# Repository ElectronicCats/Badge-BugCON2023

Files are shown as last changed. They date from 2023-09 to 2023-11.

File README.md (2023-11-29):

# Badge BugCON 2023

Badge de la resistencia BugCON 2023 #unetealaresistencia

## Características

- ESP32S3 o RP2040
- UART
- Bluetooth (ESP32S3)
- WiFi (ESP32S3)
- Baterias AA

## License
<a>
  
</a>

Diseñado por Electronic Cats para BugCON 2023

Electronic Cats invests time and resources in providing this open-source design. Please support Electronic Cats and open-source hardware by purchasing products from Electronic Cats!

Hardware released under an CERN Open Hardware Licence v1.2. See the LICENSE_HARDWARE file for more information.

Electronic Cats and BugCON is a registered trademark. Please do not use if you sell these PCBs.

Sept 2023

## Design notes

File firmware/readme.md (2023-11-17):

# Badge BugCON 2023

Link: https://github.com/ElectronicCats/Badge-BugCON2023

Author(s): Francisco Torres

Last updated: 2023/11/09

## Developer guide

## Setup

### Libraries required

Install the following libraries:

- [Adafruit GFX Library](https://www.arduino.cc/reference/en/libraries/adafruit-gfx-library/)
- [Adafruit BusIO](https://www.arduino.cc/reference/en/libraries/adafruit-busio/)
- [Adafruit NeoPixel](https://www.arduino.cc/reference/en/libraries/adafruit-neopixel/)
- [Adafruit SSD1306](https://www.arduino.cc/reference/en/libraries/adafruit-ssd1306/)
- [ezButton](https://www.arduino.cc/reference/en/libraries/ezbutton/)
- [ArduinoUniqueID](https://www.arduino.cc/reference/en/libraries/arduinouniqueid/)
- [Adafruit SH110X](https://www.arduino.cc/reference/en/libraries/adafruit-sh110x/)

> You can install these libraries using the Arduino IDE Library Manager (Sketch > Include Library > Manage Libraries...).

Versions used in this project:

```bash
Used library         Version    
Adafruit GFX Library 1.11.7
Adafruit BusIO       1.14.3
Wire
SPI
Adafruit NeoPixel    1.11.0
Adafruit SH110X      2.1.8
Adafruit SSD1306     2.5.7
ezButton             1.0.4
ArduinoUniqueID      1.3.0
```

> You can use latest versions of these libraries.

### Modify I2C pins

In order to use the SSD1306 display, you need to modify the I2C pins in `pins_arduino.h` to match the ones used in these boards.

You can locate this file in the following path (depending on your OS):

#### For RP2040

- Windows: `C:\Users\user\AppData\Local\Arduino15\packages\arduino\hardware\mbed_rp2040\4.0.6\variants\RASPBERRY_PI_PICO\pins_arduino.h`
- Linux: `~/.arduino15/packages/arduino/hardware/mbed_rp2040/4.0.6/variants/RASPBERRY_PI_PICO/pins_arduino.h`
- macOS: `~/Library/Arduino15/packages/arduino/hardware/mbed_rp2040/4.0.6/variants/RASPBERRY_PI_PICO/pins_arduino.h`

You can keep the original pins commented out, and add the following lines:

```cpp
// Wire
// #define PIN_WIRE_SDA        (4u)
// #define PIN_WIRE_SCL        (5u)
#define PIN_WIRE_SDA        (12u)
#define PIN_WIRE_SCL        (13u)
```

#### For ESP32-S3

- Windows: `C:\Users\user\AppData\Local\Arduino15\packages\esp32\hardware\esp32\2.0.11\variants\esp32s3\pins_arduino.h`
- Linux: `~/.arduino15/packages/esp32/hardware/esp32/2.0.11/variants/esp32s3/pins_arduino.h`
- macOS: `~/Library/Arduino15/packages/esp32/hardware/esp32/2.0.11/variants/esp32s3/pins_arduino.h`

You can keep the original pins commented out, and add the following lines:

```cpp
// static const uint8_t SDA = 8;
// static const uint8_t SCL = 9;
static const uint8_t SDA = 3;
static const uint8_t SCL = 4;
```

### Fix SSD1306 error

Try to compile the project, if you get the following error:

```bash
❯ make compile BOARD=rp2040
arduino-cli compile --fqbn arduino:mbed_rp2040:pico --export-binaries
/Users/deimos/Documents/Arduino/libraries/Adafruit_SSD1306/Adafruit_SSD1306.cpp:42:10: fatal error: pgmspace.h: No such file or directory
 #include <pgmspace.h>
          ^~~~~~~~~~~~
compilation terminated.
```

You need to fix the following error by commenting out the following line in `Adafruit_SSD1306.cpp`:

```cpp
#include <avr/pgmspace.h>
#elif defined(ESP8266) || defined(ESP32) || defined(ARDUINO_ARCH_RP2040)
// #include <pgmspace.h>
#else
```

> More about this error: https://github.com/adafruit/Adafruit_SSD1306/issues/259

### Production

In `hardware.h` change the following lines:

```cpp
// #define BUTTON_RIGHT 26  // GPIO26 -> For development in Raspberry Pi Pico
#define BUTTON_RIGHT 25  // GPIO25 -> For production in BugCON badge

// #define NEOPIXELS_PIN 16  // GPIO23 -> For development in Raspberry Pi Pico
#define NEOPIXELS_PIN 23  // For production in BugCON badge
```

If `MININO` is defined, commented out:

```cpp
#ifdef USB_VID
    #define BOARD_NAME "ESP32-S3"
    #define ESP32_S3
    // #define MININO
#else
```

Disable waiting for serial port in `menu.cpp` in `begin()` function:

```cpp
debug.waitForSerialConnection();
```

### Compile and flash

Generate binaries for each board:

```bash
make compile BOARD=rp2040
```

```bash
make compile BOARD=esp32s3
```

Compile and flash the binaries to the boards:

```bash
make all BOARD=rp2040
```

```bash
make all BOARD=esp32s3
```

> Note: Make sure you have the correct port selected in `Makefile` for each board.
 
## Maintainer

<a
href="https://github.com/sponsors/ElectronicCats">



</a>

Electronic Cats invests time and resources providing this open source design, please support Electronic Cats and open-source hardware by purchasing products from Electronic Cats!

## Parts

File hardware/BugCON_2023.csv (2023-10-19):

# | Reference | Qty | Value | Footprint | DNP | LCSC# | manf#
1 | C1 | 1 | 1uF | Capacitor_SMD:C_0603_1608Metric |  | C15849
2 | C2, C3, C4, C5 | 4 | 10uF | Capacitor_SMD:C_0603_1608Metric |  | C85713
3 | D1 | 1 | MBR120 | Diode_SMD:D_SOD-123F |  | C130880 | MBR120LSF
4 | F1 | 1 | 0.5A | Fuse:Fuse_0805_2012Metric |  | - | MFU0805FF00500P100
5 | J1 | 1 | Conn_01x04_Pin | Connector_PinSocket_2.54mm:PinSocket_1x04_P2.54mm_Vertical |  |  | Display OLED 128×32 0.91 I2C SSD1306 Blanco / Azul
6 | J2 | 1 | Conn_01x04_Pin | Connector_PinSocket_2.54mm:PinSocket_1x04_P2.54mm_Vertical
7 | J3 | 1 | Conn_01x02 | Connector_PinSocket_2.54mm:PinSocket_1x02_P2.54mm_Vertical
8 | P1 | 1 | USB_C_Plug_USB2.0 | Connectors:C393939 |  | C2760486 | TYPE-C-31-M-31
9 | Q1 | 1 | DMG3415U-7 | Package_TO_SOT_SMD:SOT-23 |  | C96616 | DMG3415U-7
10 | R1 | 1 | 10K | Resistor_SMD:R_0603_1608Metric |  | C217281 | CR-03JL7---10K
11 | R2, R3 | 2 | 5k1 | Resistor_SMD:R_0603_1608Metric |  | C191782 | ERJ3RBD5101V
12 | R4 | 1 | 100K | Resistor_SMD:R_0603_1608Metric |  | C15458 | WR06X104JTL
13 | SW1 | 1 | RESET | Button_Switch_SMD:SW_SPST_TL3342 |  | C318889
14 | SW2 | 1 | GPIO | Button_Switch_SMD:SW_SPST_TL3342 |  | C318889
15 | SW3 | 1 | ON | Footprint:JS102011SAQN |  | C393937
16 | U1 | 1 | ESP32-S3-WROOM-1U-N16 | RF_Module:ESP32-S3-WROOM-1U |  |  | ESP32-S3-WROOM-1U-N16
17 | U2 | 1 | AP2112K-3.3 | Package_TO_SOT_SMD:SOT-23-5 |  | C150742 | AP7365-33WG-7

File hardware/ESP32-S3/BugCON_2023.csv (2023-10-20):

# | Reference | Qty | Value | Footprint | DNP | LCSC# | manf# | Proveedor
1 | C1 | 1 | 1uF | Capacitor_SMD:C_0603_1608Metric |  | C15849 | CL10A105KB8NNNC | LCSC
2 | C2, C3, C4, C5 | 4 | 10uF | Capacitor_SMD:C_0603_1608Metric |  | C85713 | CL10A106MP8NNNC | LCSC
3 | C6, C7, C8, C9 | 4 | 0.1uF | Capacitor_SMD:C_0603_1608Metric |  | C42998 | 0603F104M500NT | LCSC
4 | D1 | 1 | MBR120 | Diode_SMD:D_SOD-123F |  | C130880 | MBR120LSF | LCSC
5 | D2, D3, D5, D6 | 4 | WS2812B | FootprintsB:LED-SMD_4P-L3.5-W3.5-TL_WS2812B |  | C527089 | WS2812B-Mini | LCSC
6 | F1 | 1 | 0.5A | Fuse:Fuse_0805_2012Metric |  | - | MFU0805FF00500P100 | MOUSER
7 | J1 | 1 | Conn_01x04_Pin | Connector_PinSocket_2.54mm:PinSocket_1x04_P2.54mm_Vertical |  |  | Display OLED 128×32 0.91 I2C SSD1306 Blanco / Azul | Unit Electronics
8 | J3 | 1 | Conn_01x02 | FootprintsB:BAT_12BH331P-GR |  |  | 12BH331P-GR | MOUSER
9 | J4, J5 | 2 | Conn_01x01_Pin | Connector_PinHeader_1.00mm:PinHeader_1x01_P1.00mm_Horizontal | DNP
10 | J6 | 1 | SERIAL | Connector_PinSocket_2.54mm:PinSocket_1x03_P2.54mm_Vertical
11 | P1 | 1 | USB_C_Plug_USB2.0 | FootprintsB:C393939 |  | C2765186 | TYPE-C 16PIN 2MD(073) | LCSC
12 | Q1 | 1 | DMG3415U-7 | Package_TO_SOT_SMD:SOT-23 |  | C96616 | DMG3415U-7 | LCSC
13 | R1 | 1 | 10K | Resistor_SMD:R_0603_1608Metric |  | C309083 | ARG03BTC1002 | LCSC
14 | R2, R3 | 2 | 5k1 | Resistor_SMD:R_0603_1608Metric |  | C191782 | ERJ3RBD5101V | LCSC
15 | R4 | 1 | 100K | Resistor_SMD:R_0603_1608Metric |  | C15458 | 0603WAJ0104T5E | LCSC
16 | R9 | 1 | 470 | Resistor_SMD:R_0603_1608Metric |  | C103661 | RTT03471JTP
17 | SW1 | 1 | RESET | Button_Switch_SMD:SW_SPST_TL3342 |  | C318889 | TS-1187A-C-C-B | LCSC
18 | SW2 | 1 | GPIO | Button_Switch_SMD:SW_SPST_TL3342 |  | C318889 | TS-1187A-C-C-B | LCSC
19 | SW3 | 1 | ON | FootprintsB:SW-TH_SK12D07VG4 |  | C393937 | SK12D07VG4 | LCSC
20 | U1 | 1 | ESP32-S3-WROOM-1-N4 | FootprintsB:XCVR_ESP32-S3-WROOM-1-N8R2 |  |  | ESP32-S3-WROOM-1-N4 | MOUSER
21 | U2 | 1 | AP2112K-3.3 | Package_TO_SOT_SMD:SOT-23-5 |  | C51118 | AP2112K-3.3TRG1 | LCSC

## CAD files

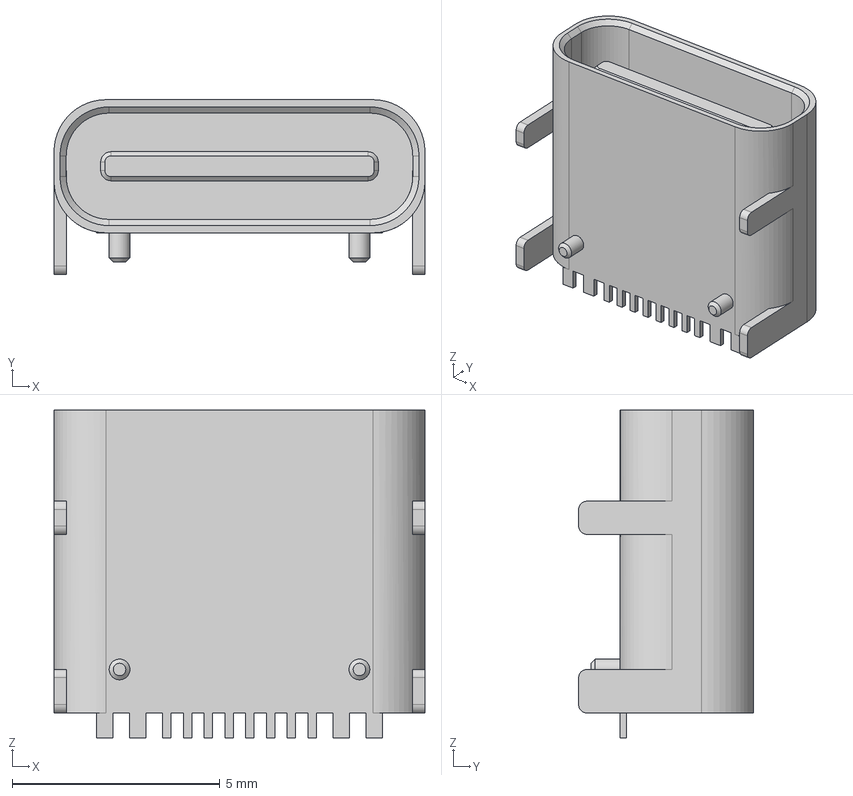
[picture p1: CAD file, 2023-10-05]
hardware/ESP32-S3/FootprintsB/3D/HRO TYPE-C-31-M-12.step
8.94 x 4.21 x 7.90 mm

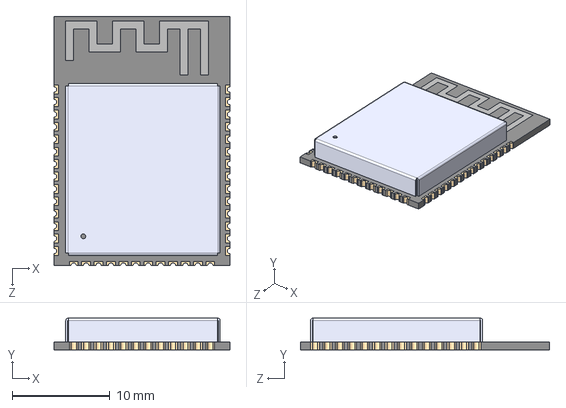
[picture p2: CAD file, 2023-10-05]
hardware/ESP32-S3/FootprintsB/3D/ESP32-S3-WROOM-1-N8R2.step
18.0 x 3.25 x 25.5 mm

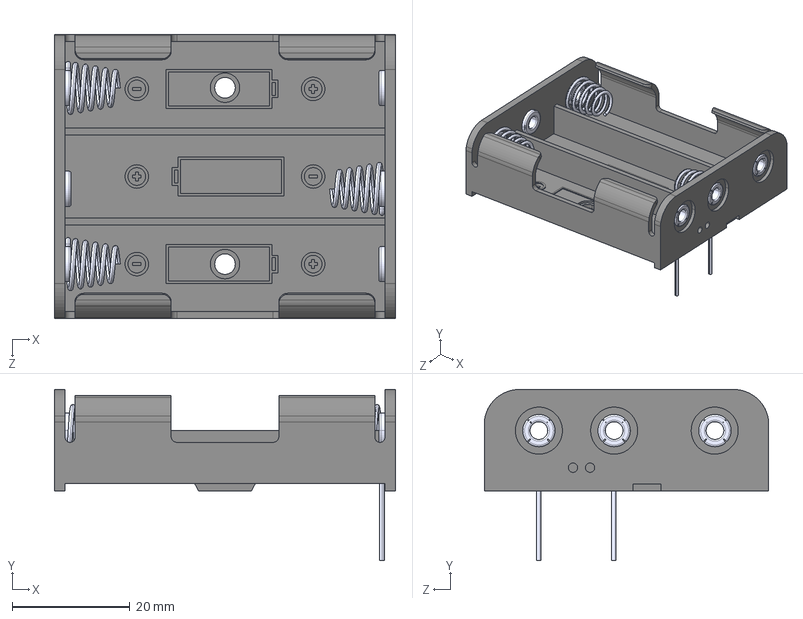
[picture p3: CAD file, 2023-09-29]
hardware/ESP32-S3/FootprintsB/3D/12BH331P-GR--3DModel-STEP-56544.STEP
58.0 x 29.1 x 48.3 mm

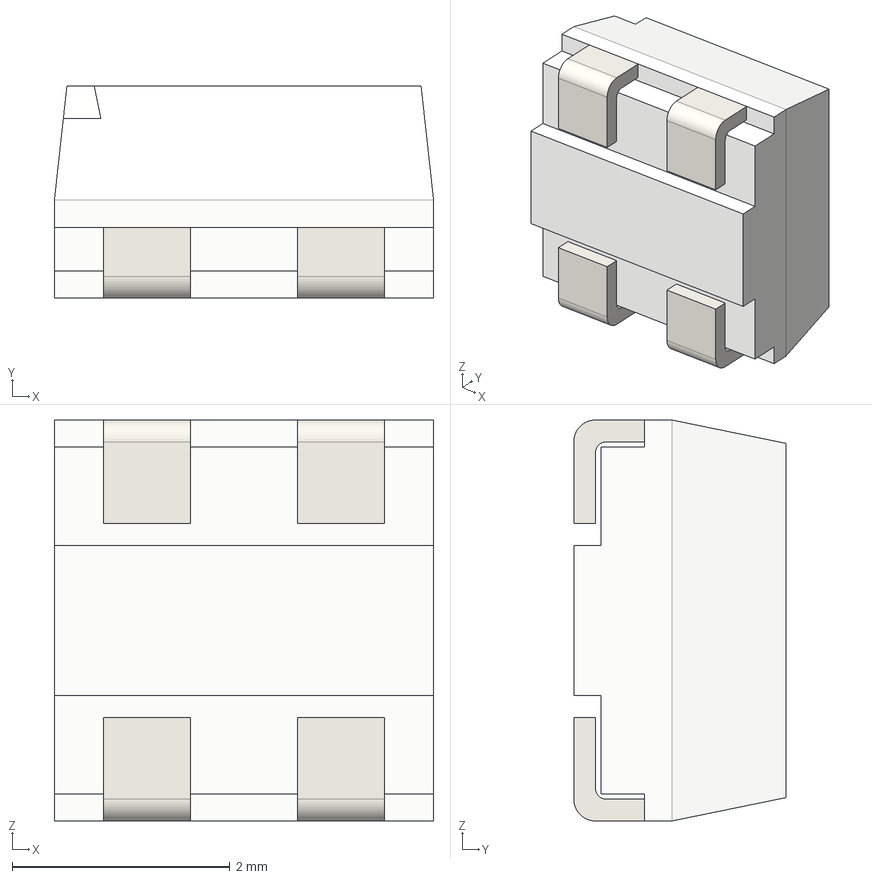
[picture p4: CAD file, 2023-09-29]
hardware/ESP32-S3/FootprintsB/3D/SMD WS2812B Mini.step
3.48 x 1.95 x 3.68 mm

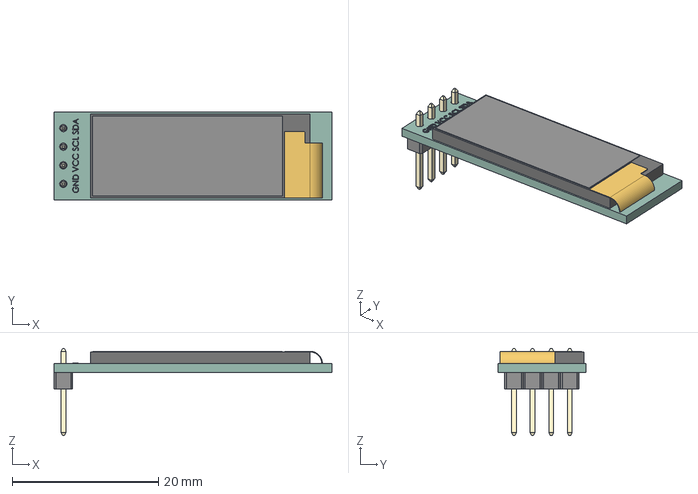
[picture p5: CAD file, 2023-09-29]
hardware/ESP32-S3/FootprintsB/3D/128x32-OLED.STEP
38.0 x 12.0 x 11.9 mm

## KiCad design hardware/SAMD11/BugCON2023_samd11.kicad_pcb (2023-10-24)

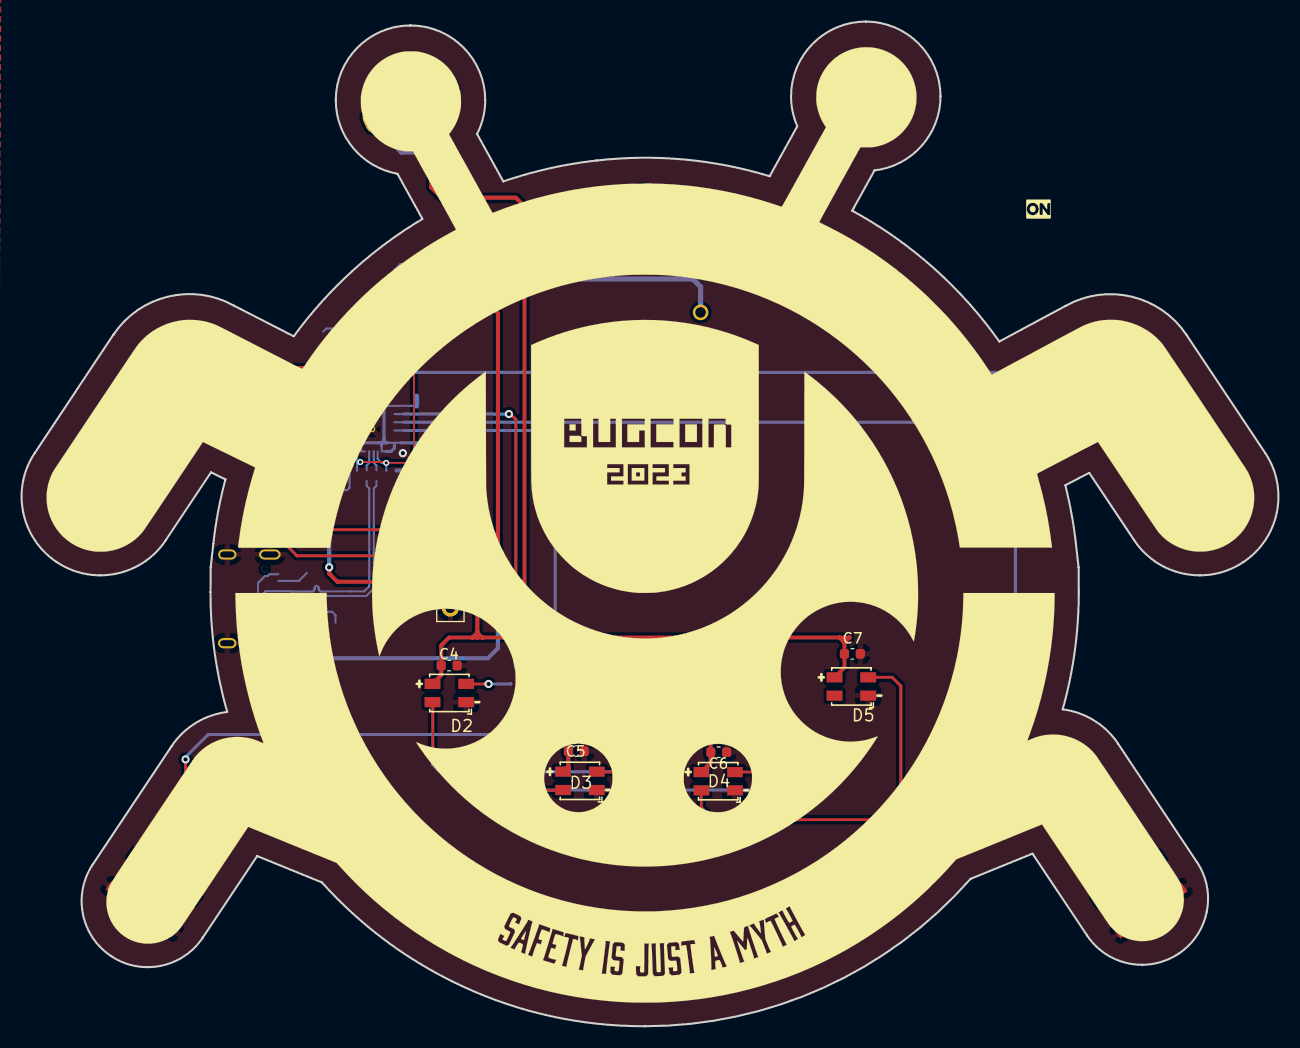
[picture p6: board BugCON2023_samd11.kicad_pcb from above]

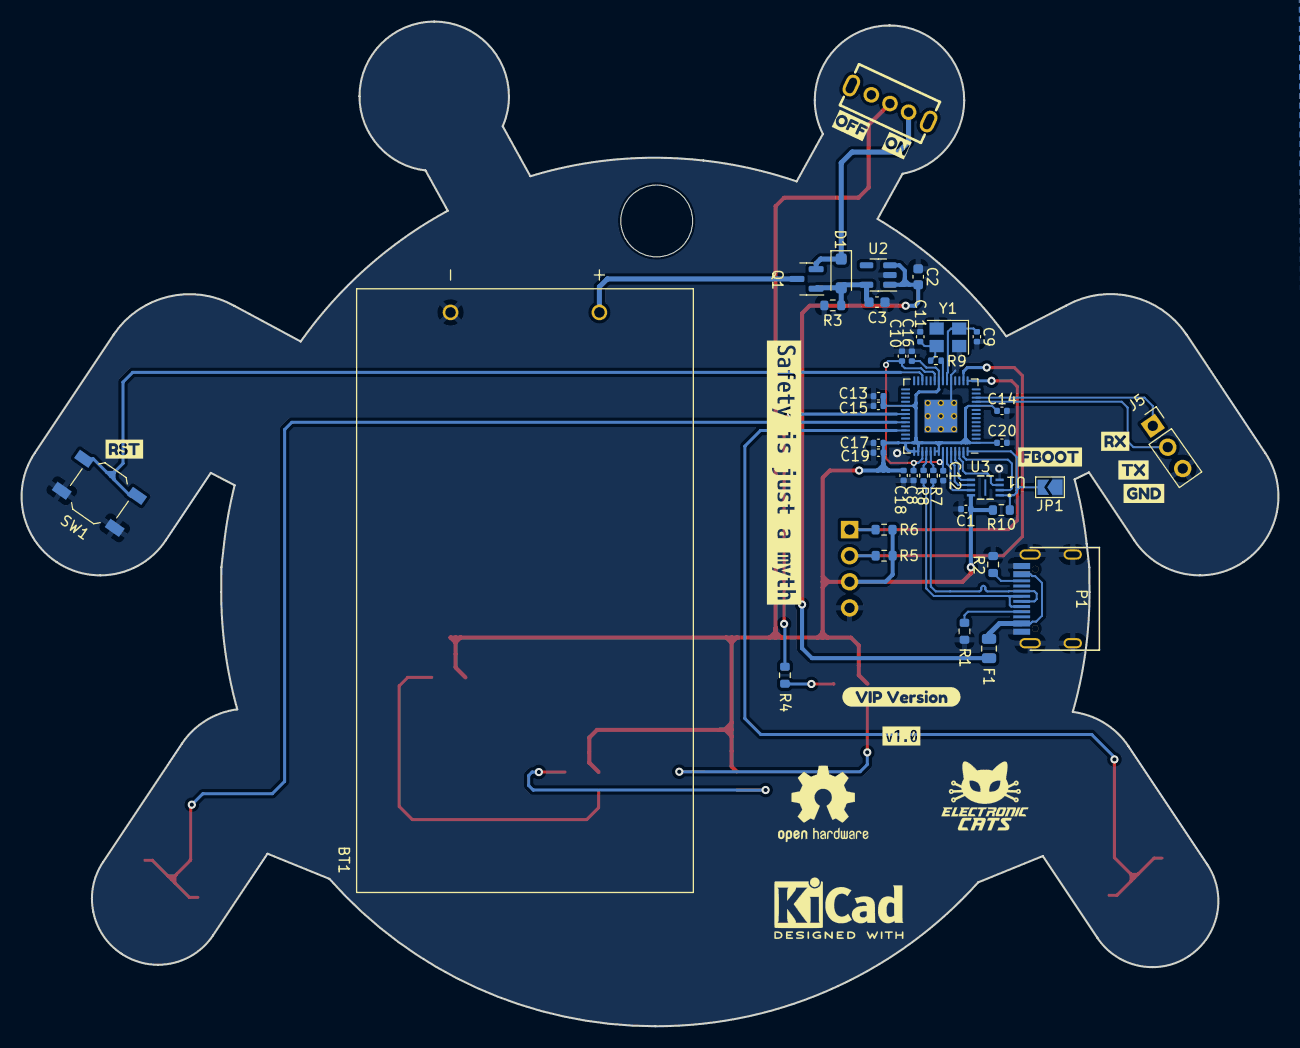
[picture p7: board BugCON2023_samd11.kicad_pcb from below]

Board: 2 copper layers, 122.4 x 97.9 mm, 63 parts (49 on the bottom side), 35 nets.

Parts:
BT1: Battery_Cell; BAT_2462
C1, C10, C12, C14, C15, C16, C17, C18, C19, C20: 0.1uF; C_0402_1005Metric
C2, C3: 10uF; C_0603_1608Metric
C4, C5, C6, C7: 0.1uF; C_0603_1608Metric
C8, C13: 1uF; C_0402_1005Metric
C9, C11: 27pF; C_0402_1005Metric
D1: MBR120; D_SOD-123F
D2, D3, D4, D5: WS2812B; LED-SMD_4P-L3.5-W3.5-TL_WS2812B
F1: 0.5A; Fuse_0805_2012Metric
J1: I2C; PinSocket_1x04_P2.54mm_Vertical
J5: Serial; PinSocket_1x03_P2.54mm_Vertical
JP1: BOOT; SolderJumper-2_P1.3mm_Open_TrianglePad1.0x1.5mm
P1: USB_C_Plug_USB2.0; C393939
Q1: DMG3415U-7; SOT-23
R1, R2: 5k1; R_0603_1608Metric
R3: 100K; R_0603_1608Metric
R4: 470; R_0603_1608Metric
R5, R6: 4.7; R_0603_1608Metric
R7, R8: 27; R_0402_1005Metric
R9: 1k; R_0402_1005Metric
R10: 10K; R_0603_1608Metric
Ref**: Val**; Bugcon_svg
SW1: RESET; SW_SPST_TL3342
SW2: ON; SW-TH_SK12D07VG4
SW3, SW4: SW_Push; SW_SPST_TL3342
U1: W25Q16JV; W25Q16JVUXIQ_WIN
U2: AP2112K-3.3; SOT-23-5
U3: RP2040; QFN-56-1EP_7x7mm_P0.4mm_EP3.2x3.2mm
Y1: 12MHz; Crystal_SMD_3225-4Pin_3.2x2.5mm
kibuzzard-652DCDAF: G***; kibuzzard-652DCDAF
kibuzzard-652DCDD3: G***; kibuzzard-652DCDD3
kibuzzard-652DCDF1: G***; kibuzzard-652DCDF1
kibuzzard-652EA30A: G***; kibuzzard-652EA30A
kibuzzard-652EA51A, kibuzzard-652EA51A#2: G***; kibuzzard-652EA51A
kibuzzard-6536E42E: G***; kibuzzard-6536E42E
kibuzzard-6536E385: G***; kibuzzard-6536E385
kibuzzard-6536E415: G***; kibuzzard-6536E415
kibuzzard-6536E422: G***; kibuzzard-6536E422
kibuzzard-6536E471: G***; kibuzzard-6536E471
kibuzzard-6537FB4E: G***; kibuzzard-6537FB4E

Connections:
+1V2: C8.1, C10.1, C12.1, U3.23 (DVDD), U3.45 (VREG_VOUT), U3.50 (DVDD)
+3.3V: C1.1, C4.2, C5.2, C6.2, C7.2, C13.1, C14.1, C15.1, C16.1, C17.1, C18.1, C19.1, C20.1, D2.1 (VDD), D3.1 (VDD), D4.1 (VDD), D5.1 (VDD), J1.3, R5.2, R6.1, R10.1, SW2.2 (B), U1.8 (VCC), U3.1 (IOVDD), U3.10 (IOVDD), U3.22 (IOVDD), U3.33 (IOVDD), U3.42 (IOVDD), U3.43 (ADC_AVDD), U3.44 (VREG_IN), U3.48 (USB_VDD), U3.49 (IOVDD)
+3V3: C3.1, D1.2 (A), Q1.1 (G), R3.1, U2.5 (VOUT)
+BATT: BT1.1 (+), Q1.3 (D)
/D+: P1.A6 (D+), R7.1
/D-: P1.A7 (D-), R8.1
/PB1: SW3.1, U3.39 (GPIO27_ADC1)
/PB2: SW4.1, U3.37 (GPIO25)
/PIN: R4.1, U3.35 (GPIO23)
/QSPI_SCK: U1.6 (CLK), U3.52 (QSPI_SCLK)
/QSPI_SD0: U1.5 (DI(IO0)), U3.53 (QSPI_SD0)
/QSPI_SD1: U1.2 (DO(IO1)), U3.55 (QSPI_SD1)
/QSPI_SD2: U1.3 (IO2), U3.54 (QSPI_SD2)
/QSPI_SD3: U1.7 (IO3), U3.51 (QSPI_SD3)
/QSPI_SS: JP1.2 (B), R10.2, U1.1 (~CS), U3.56 (QSPI_SS)
/RD+: R7.2, U3.47 (USB_DP+)
/RD-: R8.2, U3.46 (USB_DM-)
/RESET: SW1.1, U3.26 (RUN)
/RX: J5.1, U3.12 (GPIO9)
/SCL: J1.2, R5.1, U3.16 (GPIO13)
/SDA: J1.1, R6.2, U3.15 (GPIO12)
/TX: J5.2, U3.11 (GPIO8)
GND: BT1.2 (-), C1.2, C2.2, C3.2, C4.1, C5.1, C6.1, C7.1, C8.2, C9.2, C10.2, C11.2, C12.2, C13.2, C14.2, C15.2, C16.2, C17.2, C18.2, C19.2, C20.2, D2.3 (VSS), D3.3 (VSS), D4.3 (VSS), D5.3 (VSS), J1.4, J5.3, JP1.1 (A), P1.A1 (GND), P1.S1 (SHIELD), R1.1, R2.1, R3.2, SW1.2, SW3.2, SW4.2, U1.4 (GND), U2.2 (GND), U3.19 (TESTEN), U3.57 (GND), Y1.2, Y1.4
unnamed: C11.1, R9.1, Y1.3
unnamed: D1.1 (K), Q1.2 (S), SW2.1 (A)
unnamed: D2.4 (DIN), R4.2
unnamed: D2.2 (DOUT), D3.4 (DIN)
unnamed: D3.2 (DOUT), D4.4 (DIN)
unnamed: D4.2 (DOUT), D5.4 (DIN)
unnamed: F1.1, P1.A4 (VBUS)
unnamed: P1.A5 (CC), R1.2
unnamed: P1.B5 (VCONN), R2.2
unnamed: C9.1, U3.20 (XIN), Y1.1
unnamed: R9.2, U3.21 (XOUT)
VBUS: C2.1, F1.2, U2.1 (VIN), U2.3 (EN)

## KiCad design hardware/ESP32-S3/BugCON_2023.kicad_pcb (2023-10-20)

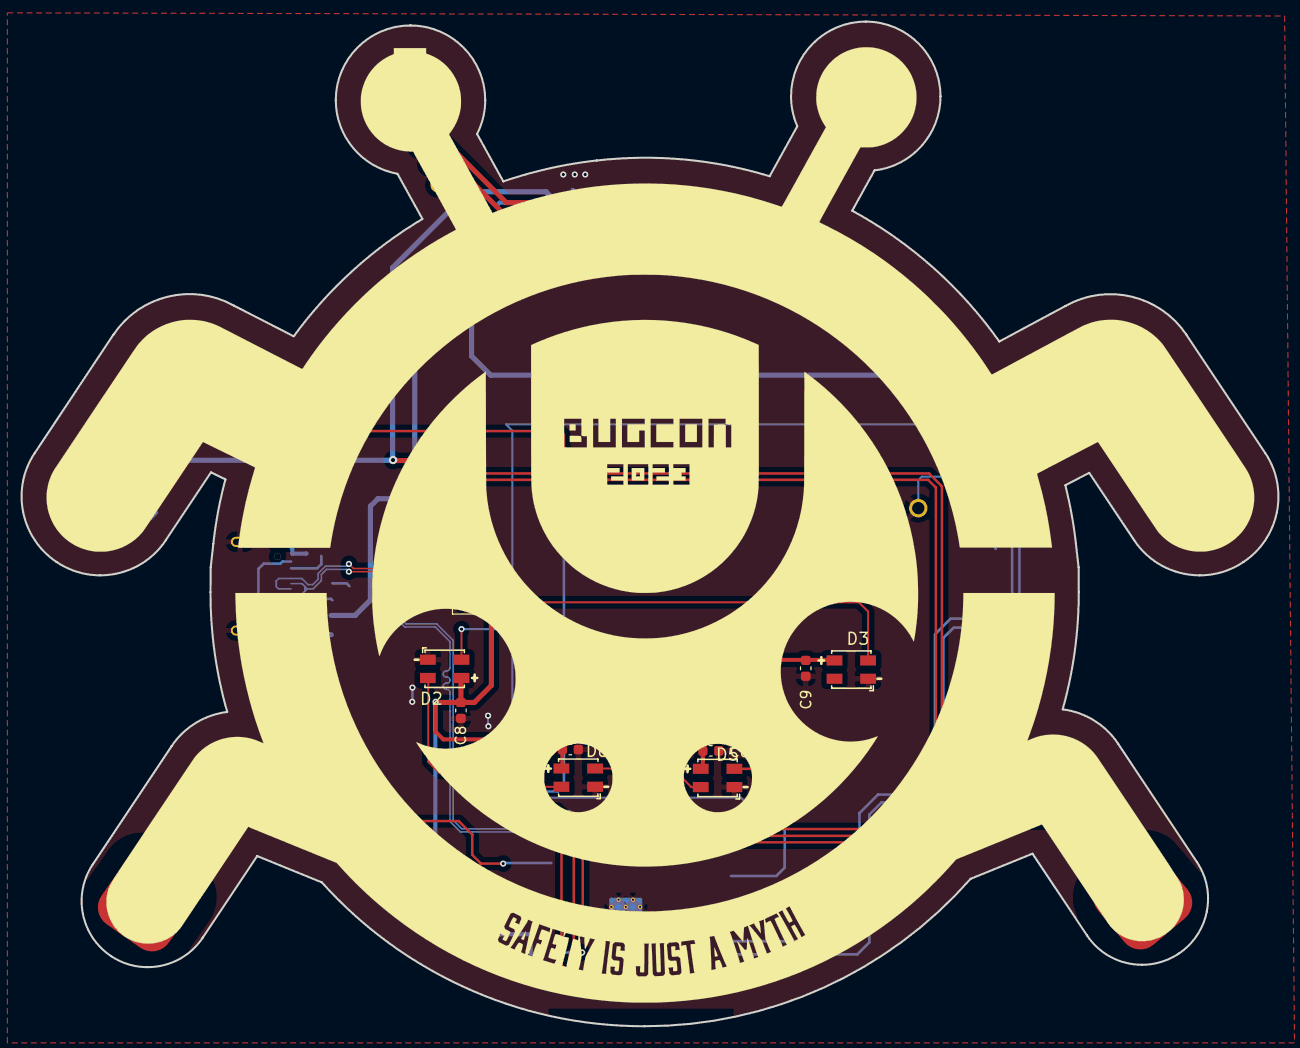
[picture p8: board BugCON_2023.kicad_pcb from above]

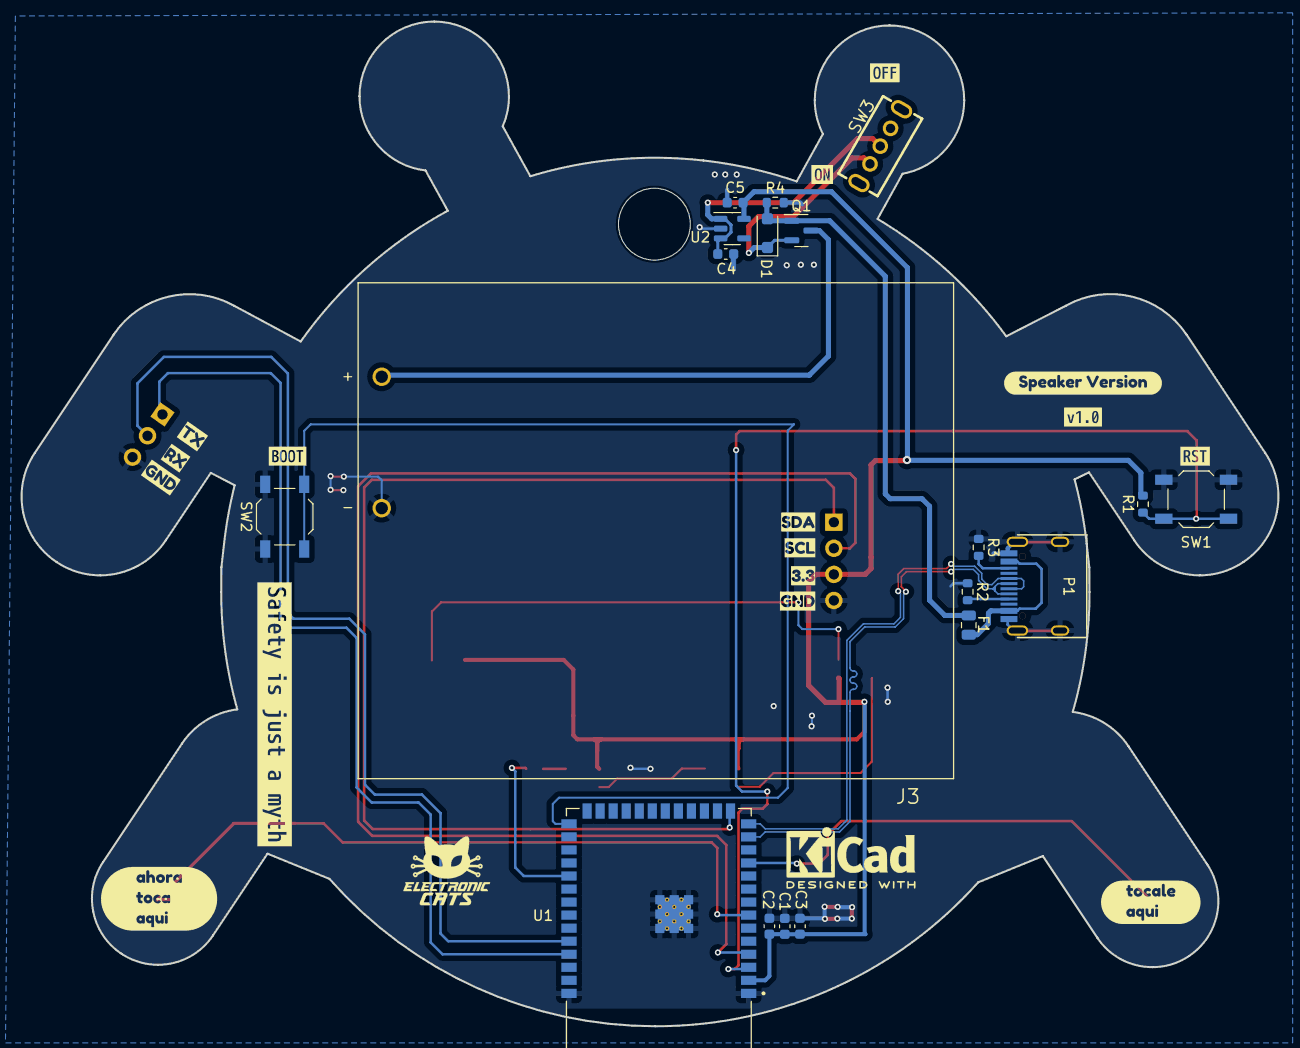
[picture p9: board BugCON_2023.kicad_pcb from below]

Board: 2 copper layers, 122.4 x 97.9 mm, 50 parts (35 on the bottom side), 24 nets.

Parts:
C1: 1uF; C_0603_1608Metric
C2, C3, C4, C5: 10uF; C_0603_1608Metric
C6, C7, C8, C9: 0.1uF; C_0603_1608Metric
D1: MBR120; D_SOD-123F
D2, D3, D5, D6: WS2812B; LED-SMD_4P-L3.5-W3.5-TL_WS2812B
F1: 0.5A; Fuse_0805_2012Metric
J1: Conn_01x04_Pin; PinSocket_1x04_P2.54mm_Vertical
J3: Conn_01x02; BAT_12BH331P-GR
J4, J5: Conn_01x01_Pin; PinHeader_1x01_P1.00mm_Horizontal
J6: SERIAL; PinSocket_1x03_P2.54mm_Vertical
P1: USB_C_Plug_USB2.0; C393939
Q1: DMG3415U-7; SOT-23
R1: 10K; R_0603_1608Metric
R2, R3: 5k1; R_0603_1608Metric
R4: 100K; R_0603_1608Metric
R9: 470; R_0603_1608Metric
Ref**: Val**; Bugcon_svg
SW1: RESET; SW_SPST_TL3342
SW2: GPIO; SW_SPST_TL3342
SW3: ON; SW-TH_SK12D07VG4
U1: ESP32-S3-WROOM-1-N4; XCVR_ESP32-S3-WROOM-1-N8R2
U2: AP2112K-3.3; SOT-23-5
kibuzzard-652D8C8F: G***; kibuzzard-652D8C8F
kibuzzard-652D8CA2: G***; kibuzzard-652D8CA2
kibuzzard-652EA3B8: G***; kibuzzard-652EA3B8
kibuzzard-652EA5CF: G***; kibuzzard-652EA5CF
kibuzzard-652EA5F7: G***; kibuzzard-652EA5F7
kibuzzard-652EA30A: G***; kibuzzard-652EA30A
kibuzzard-652EA32D: G***; kibuzzard-652EA32D
kibuzzard-652EA37F: G***; kibuzzard-652EA37F
kibuzzard-652EA51A: G***; kibuzzard-652EA51A
kibuzzard-652EA56E: G***; kibuzzard-652EA56E
kibuzzard-652EA350: G***; kibuzzard-652EA350
kibuzzard-652EA580: G***; kibuzzard-652EA580
kibuzzard-6515D6F9: G***; kibuzzard-6515D6F9
kibuzzard-6515D7CD: G***; kibuzzard-6515D7CD
kibuzzard-6515D70B: G***; kibuzzard-6515D70B
kibuzzard-6515D795, kibuzzard-6515D795#2: G***; kibuzzard-6515D795

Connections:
+3V3: C1.1, C2.1, C3.1, C5.1, C6.2, C7.2, C8.2, C9.2, D2.1 (VDD), D3.1 (VDD), D5.1 (VDD), D6.1 (VDD), J1.3, R1.2, U1.2 (3V3), U2.5 (VOUT)
+BATT: J3.1, Q1.3 (D)
/BOOT: SW2.2, U1.27 (IO0)
/D+: P1.A6 (D+), U1.14 (IO20)
/D-: P1.A7 (D-), U1.13 (IO19)
/PIN: R9.1, U1.31 (IO38)
/RST: R1.1, SW1.2, U1.3 (EN)
/RX: J6.2, U1.36 (RXD0)
/SCL: J1.2, U1.4 (IO4)
/SDA: J1.1, U1.15 (IO3)
/TCH1: J5.1, U1.7 (IO7)
/TCH2: J4.1, U1.11 (IO18)
/TX: J6.1, U1.37 (TXD0)
GND: C1.2, C2.2, C3.2, C4.2, C5.2, C6.1, C7.1, C8.1, C9.1, D2.3 (VSS), D3.3 (VSS), D5.3 (VSS), D6.3 (VSS), J1.4, J3.2, J6.3, P1.A1 (GND), P1.S1 (SHIELD), R2.1, R3.1, R4.2, SW1.1, SW2.1, U1.1 (GND), U1.40 (GND), U2.2 (GND)
unnamed: D1.1 (K), Q1.2 (S), SW3.1 (A)
unnamed: D2.4 (DIN), D6.2 (DOUT)
unnamed: D2.2 (DOUT), D3.4 (DIN)
unnamed: D5.4 (DIN), R9.2
unnamed: D5.2 (DOUT), D6.4 (DIN)
unnamed: F1.1, P1.A4 (VBUS)
unnamed: P1.A5 (CC), R2.2
unnamed: P1.B5 (VCONN), R3.2
unnamed: C4.1, SW3.2 (B), U2.1 (VIN), U2.3 (EN)
VBUS: D1.2 (A), F1.2, Q1.1 (G), R4.1

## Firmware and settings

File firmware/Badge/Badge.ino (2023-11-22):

// /*********************************************************************************
//   Firmware for BugCON Badge 2023
//   by Francisco Torres, Electronic Cats (https://electroniccats.com/)
//   Date: 2023/11/09

//   This program demonstrates how to use several features of the BugCON Badge 2023
//   by Electronic Cats
//   https://github.com/ElectronicCats/Badge-BugCON2023.git

//   Development environment specifics:
//   IDE: Visual Studio Code + Arduino CLI Version 0.34.2
//   Hardware Platform:
//   BugCON Badge, VIP edition
//   - RP2040
//   BugCON Badge, Speaker edition
//   - ESP32-S3

//   Electronic Cats invests time and resources providing this open source code,
//   please support Electronic Cats and open-source hardware by purchasing
//   products from Electronic Cats!

//   This code is beerware; if you see me (or any other Electronic Cats
//   member) at the local, and you've found our code helpful,
//   please buy us a round!
//   Distributed as-is; no warranty is given.
// ***********************************************************************************/
// #include "server.h"
#include "terminal.h"
#include "index.html.h"
#include "main.js.h"
#include "styles.css.h"

#ifdef ESP32
#include <WiFi.h>
#include <WiFiAP.h>
#include <WiFiClient.h>

enum URL {
  INDEX_HTML = 0,
  MAIN_JS,
  STYLES_CSS,
  NOT_FOUND
};

int port = 80;
WiFiServer server(port);
String defaultSSID;
String defaultPassword;
int status;
URL webRequest = INDEX_HTML;
Debug &debug = Debug::getInstance();
void setupWiFi();
void loadPageContent(WiFiClient client);
void showPageContent(WiFiClient client, const char *pageContent);
String decodeURL(char *url);
void updateWebRequest(String url);
void handleRequests();
void handleURLParameters(String url);
void runServer();
String ipToString(IPAddress ip);
#endif

void setup() {
  menu.begin();
#ifdef ESP32
  setupWiFi();
#endif
}

void loop() {
  menu.loop();
#ifdef RP2040
  if (menu.isTerminalEnabled()) {
    terminalSetup();
    terminalLoop();
    menu.disableTerminal();
  }
#endif

#ifdef ESP32
  if (menu.isServerActived())
    runServer();
#endif
}

#ifdef ESP32
void setupWiFi() {
#ifdef ESP32
  debug.println("");
  debug.println("Configuring access point...");
  defaultSSID += menu.speaker.getSSID();
  defaultPassword = menu.speaker.getPassword();

  // You can remove the password parameter if you want the AP to be open.
  // a valid password must have more than 7 characters
  if (!WiFi.softAP(defaultSSID.c_str(), defaultPassword.c_str())) {
    log_e("Soft AP creation failed.");
    while (1)
      ;
  }
  IPAddress myIP = WiFi.softAPIP();
  debug.print("AP IP address: ");
  debug.println(ipToString(myIP));
  menu.speaker.setIP(ipToString(WiFi.softAPIP()));
  server.begin();

  debug.println("Server started");
#endif
}

void runServer() {
  WiFiClient client = server.available();  // listen for incoming clients

  if (client) {  // if you get a client,
    unsigned long speedTestTime = millis();
    String currentLine = "";  // make a String to hold incoming data from the client

    while (client.connected()) {  // loop while the client's connected
      if (client.available()) {   // if there's bytes to read from the client,
        char c = client.read();   // read a byte, then
        // debug.write(c);  // print it out the debug monitor

        if (c == '\n') {  // if the byte is a newline character
          if (currentLine.length() == 0) {
            loadPageContent(client);
            break;
          } else {
            currentLine = "";  // if you got a newline, then clear currentLine:
          }
        } else if (c != '\r') {  // if you got anything else but a carriage return character,
          currentLine += c;      // add it to the end of the currentLine
        }

        // Only check for URL if it's a GET <url options> HTTP
        if (currentLine.startsWith("GET /") && currentLine.endsWith("HTTP/1.1")) {
          String url = currentLine.substring(4, currentLine.indexOf("HTTP/1.1"));
          debug.println("\nRequest: " + currentLine);
          debug.println("URL: " + url);

          updateWebRequest(url);
          handleURLParameters(url);
        }
      }
    }
    client.stop();
    // debug.println("client disconnected");
    // debug.println("Time to run server: " + String(millis() - speedTestTime) + " ms");
  }

  handleRequests();
}

void loadPageContent(WiFiClient client) {
  static URL currentHTML;

  switch (webRequest) {
    case STYLES_CSS:
      showPageContent(client, styles_css);
      webRequest = currentHTML;
      break;
    case MAIN_JS:
      showPageContent(client, main_js);
      webRequest = currentHTML;
      break;
    case INDEX_HTML:
      showPageContent(client, index_html);
      currentHTML = INDEX_HTML;
      break;
    default:
      showPageContent(client, index_html);
      currentHTML = INDEX_HTML;
      break;
  }
}

void showPageContent(WiFiClient client, const char *pageContent) {
  String contentType;
  if (webRequest == INDEX_HTML) {
    contentType = "text/html";
  } else if (webRequest == STYLES_CSS) {
    contentType = "text/css";
  } else if (webRequest == MAIN_JS) {
    contentType = "application/javascript";
  }

  client.println("HTTP/1.1 200 OK");
  client.println("Content-type:" + contentType);
  client.println();

  // Create a temporary string to hold the page content
  char tempString[1001];
  tempString[1000] = 0;
  // Flag to indicate if we've reached the end of the page content
  boolean lastString = false;
  // Pointer to determine where we are in the page content
  char *charPtr = (char *)pageContent;

  // Loop to read the page content in chunks of 1000 bytes
  while (1) {
    for (int i = 0; i < 1000; i++) {
      // Check if we've reached the end of the page content
      if ((byte)*charPtr == 0) {
        lastString = true;
        tempString[i] = 0;
      }
      // Copy the page content to the temporary string
      tempString[i] = *charPtr;
      charPtr++;
    }
    // Send the temporary string to the client
    client.print(tempString);
    if (lastString == true)
      break;  // Exit the loop if we've reached the end of the page content
  }

  client.println("");  // Send a blank line to indicate the end of the page content
}

String decodeURL(char *url) {
  // Check if the URL starts with "%B" and return as it is.
  if (strncmp(url, "%B", 2) == 0) {
    String decodedURL = String(url);
    decodedURL.trim();
    decodedURL.replace("+", " ");
    return decodedURL;
  }

  // Create two pointers that point to the start of the data
  char *leader = url;
  char *follower = leader;

  // While we're not at the end of the string (current character not NULL)
  while (*leader) {
    // Check to see if the current character is a %
    if (*leader == '%') {
      // Grab the next two characters and move leader forwards
      leader++;
      char high = *leader;
      leader++;
      char low = *leader;

      // Convert ASCII 0-9A-F to a value 0-15
      if (high > 0x39)
        high -= 7;
      high &= 0x0f;

      // Same again for the low byte:
      if (low > 0x39)
        low -= 7;
      low &= 0x0f;

      // Combine the two into a single byte and store in follower:
      *follower = (high << 4) | low;
    } else {
      // All other characters copy verbatim
      *follower = *leader;
    }

    // Move both pointers to the next character:
    leader++;
    follower++;
  }
  // Terminate the new string with a NULL character to trim it off
  *follower = 0;

  // Return the new string
  String decodedURL = String(url);
  decodedURL.trim();
  decodedURL.replace("+", " ");
  return decodedURL;
}

void updateWebRequest(String url) {
  if (url.startsWith("/styles.css")) {
    webRequest = STYLES_CSS;
  } else if (url.startsWith("/main.js")) {
    webRequest = MAIN_JS;
  } else if (url.startsWith("/index.html?") || url.startsWith("/index.html")) {
    webRequest = INDEX_HTML;
  } else {
    webRequest = NOT_FOUND;
  }
}

void handleRequests() {
  static unsigned long detectTagsTime = millis();
}

void handleURLParameters(String url) {
  // ? is the start of request parameters
  // URL: /index.html?red=255&green=0&blue=255
  if (url.startsWith("/index.html?")) {
    String redValue = "";
    String greenValue = "";
    String blueValue = "";

    int index = url.indexOf("red=");
    if (index != -1) {
      redValue = url.substring(index + 4, url.indexOf("&green="));
    }

    index = url.indexOf("green=");
    if (index != -1) {
      greenValue = url.substring(index + 6, url.indexOf("&blue="));
    }

    index = url.indexOf("blue=");
    if (index != -1) {
      blueValue = url.substring(index + 5, url.length());
    }

    debug.println("redValue: " + redValue);
    debug.println("greenValue: " + greenValue);
    debug.println("blueValue: " + blueValue);

    int red = redValue.toInt();
    int green = greenValue.toInt();
    int blue = blueValue.toInt();

    for (int i = 0; i < NUMPIXELS; i++) {
      menu.pixels.setPixelColor(i, menu.pixels.Color(red, green, blue));
    }
    menu.pixels.show();
  }
}

String ipToString(IPAddress ip) {
  String result = "";
  for (int i = 0; i < 4; i++) {
    result += String(ip[i]);
    if (i < 3) {
      result += ".";
    }
  }
  return result;
}
#endif

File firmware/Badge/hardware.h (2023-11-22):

#ifndef HARDWARE_H
#define HARDWARE_H

#ifndef BOARD_NAME
	#ifdef USB_VID
		#define BOARD_NAME "ESP32-S3"
		#define ESP32_S3
		// #define MININO
	#else
		#define BOARD_NAME "ESP32"
		#define ESP32_DEVKIT
	#endif
#endif

#if defined(ARDUINO_ARCH_MBED_RP2040) || defined(ARDUINO_ARCH_RP2040)
#define RP2040
#endif

#if defined(ARDUINO_ARCH_RP2040)
#ifndef ARDUINO_ARCH_MBED_RP2040
#define ARCH_RP2040
#endif
#endif

#define DEBOUNCE_TIME_MS 70
#define LONG_CLICK_TIME_MS 500
#define BACK_ANIMATION_TIME_MS 150

#define BUTTON_LEFT 27   // GPIO27
// #define BUTTON_RIGHT 26  // GPIO26 -> For development in Raspberry Pi Pico
#define BUTTON_RIGHT 25  // GPIO25 -> For production in BugCON badge

#if defined(ESP32_DEVKIT)
#define TOUCH_LEFT 14    // GPIO14
#define TOUCH_RIGHT 12   // GPIO12
#elif defined(MININO)
#define TOUCH_LEFT 9    // GPIO9
#define TOUCH_RIGHT 10   // GPIO10
#else // ESP32_S3
#define TOUCH_LEFT 8    // GPIO8
#define TOUCH_RIGHT 7   // GPIO7
#endif
#define OLD_TOUCH_LEFT 18    // GPIO18

#if defined(ARDUINO_ARCH_MBED_RP2040) || defined(ARDUINO_ARCH_RP2040)
// #define NEOPIXELS_PIN 16  // GPIO23 -> For development in Raspberry Pi Pico
#define NEOPIXELS_PIN 23  // For production in BugCON badge
#elif defined(ESP32_DEVKIT)
#define NEOPIXELS_PIN 19
#elif defined(MININO)
#define NEOPIXELS_PIN 11
#else // ESP32_S3
#define NEOPIXELS_PIN 38
#endif

#define NUMPIXELS 4

#endif

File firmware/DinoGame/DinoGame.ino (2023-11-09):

/**
 * Author:    Harsh Mittal
 * Created:   10.07.2021
 * Github: www.github.com/harshmittal2210
 * Email: harshmittal2210@gmail.com
 *
 * (c) Copyright by Harsh Mittal.
 **/

// Include 
#include <Wire.h>
#include <Adafruit_GFX.h>
#include <Adafruit_SSD1306.h>
#include <Adafruit_SH110X.h>

// Defines
#define SCREEN_WIDTH 128 // OLED display width, in pixels
#define SCREEN_HEIGHT 32 // OLED display height, in pixels

#define OLED_RESET     4 // Reset pin # (or -1 if sharing Arduino reset pin)
#define SCREEN_ADDRESS 0x3C

#define DINO_WIDTH 25
#define DINO_HEIGHT 26
#define DINO_INIT_X 10 // Dino initial spawn location
// #define DINO_INIT_Y 29 // Dino initial spawn location
#define DINO_INIT_Y 5  // Nueva ubicación inicial del dinosaurio

// #define BASE_LINE_X 0
// #define BASE_LINE_Y 54
// #define BASE_LINE_X1 127
// #define BASE_LINE_Y1 54
#define BASE_LINE_X 0
#define BASE_LINE_Y 21
#define BASE_LINE_X1 127
#define BASE_LINE_Y1 21

#define TREE1_WIDTH 11
#define TREE1_HEIGHT 23
 
#define TREE2_WIDTH 22
#define TREE2_HEIGHT 23

// #define TREE_Y 35
#define TREE_Y 9

#define JUMP_PIXEL 22 // Number of pixel dino will jump
// #define JUMP_PIXEL 11

Adafruit_SSD1306 display(SCREEN_WIDTH, SCREEN_HEIGHT, &Wire, OLED_RESET);
// Adafruit_SH1106G display = Adafruit_SH1106G(SCREEN_WIDTH, SCREEN_HEIGHT, &Wire, OLED_RESET);


static const unsigned char PROGMEM dino1[]={
  // 'dino', 25x26px
0x00, 0x00, 0x00, 0x00, 0x00, 0x07, 0xfe, 0x00, 0x00, 0x06, 0xff, 0x00, 0x00, 0x0e, 0xff, 0x00, 
0x00, 0x0f, 0xff, 0x00, 0x00, 0x0f, 0xff, 0x00, 0x00, 0x0f, 0xff, 0x00, 0x00, 0x0f, 0xc0, 0x00, 
0x00, 0x0f, 0xfc, 0x00, 0x40, 0x0f, 0xc0, 0x00, 0x40, 0x1f, 0x80, 0x00, 0x40, 0x7f, 0x80, 0x00, 
0x60, 0xff, 0xe0, 0x00, 0x71, 0xff, 0xa0, 0x00, 0x7f, 0xff, 0x80, 0x00, 0x7f, 0xff, 0x80, 0x00, 
0x7f, 0xff, 0x80, 0x00, 0x3f, 0xff, 0x00, 0x00, 0x1f, 0xff, 0x00, 0x00, 0x0f, 0xfe, 0x00, 0x00, 
0x03, 0xfc, 0x00, 0x00, 0x01, 0xdc, 0x00, 0x00, 0x01, 0x8c, 0x00, 0x00, 0x01, 0x8c, 0x00, 0x00, 
0x01, 0x0c, 0x00, 0x00, 0x01, 0x8e, 0x00, 0x00
};

static const unsigned char PROGMEM tree1[]={
  // 'tree1', 11x23px
0x1e, 0x00, 0x1f, 0x00, 0x1f, 0x40, 0x1f, 0xe0, 0x1f, 0xe0, 0xdf, 0xe0, 0xff, 0xe0, 0xff, 0xe0, 
0xff, 0xe0, 0xff, 0xe0, 0xff, 0xe0, 0xff, 0xe0, 0xff, 0xc0, 0xff, 0x00, 0xff, 0x00, 0x7f, 0x00, 
0x1f, 0x00, 0x1f, 0x00, 0x1f, 0x00, 0x1f, 0x00, 0x1f, 0x00, 0x1f, 0x00, 0x1f, 0x00
};

static const unsigned char PROGMEM tree2[]={
  // 'tree2', 22x23px
0x1e, 0x01, 0xe0, 0x1f, 0x03, 0xe0, 0x1f, 0x4f, 0xe8, 0x1f, 0xff, 0xfc, 0x1f, 0xff, 0xfc, 0xdf, 
0xff, 0xfc, 0xff, 0xff, 0xfc, 0xff, 0xff, 0xfc, 0xff, 0xff, 0xfc, 0xff, 0xff, 0xfc, 0xff, 0xff, 
0xfc, 0xff, 0xef, 0xfc, 0xff, 0x83, 0xfc, 0xff, 0x03, 0xfc, 0xff, 0x03, 0xf8, 0x7f, 0x03, 0xe0, 
0x1f, 0x03, 0xe0, 0x1f, 0x03, 0xe0, 0x1f, 0x03, 0xe0, 0x1f, 0x03, 0xe0, 0x1f, 0x03, 0xe0, 0x1f, 
0x03, 0xe0, 0x1f, 0x03, 0xe0
};

void setup() {
  // put your setup code here, to run once:
  Serial.begin(9600);

  // SSD1306_SWITCHCAPVCC = generate display voltage from 3.3V internally
  if(!display.begin(SSD1306_SWITCHCAPVCC, SCREEN_ADDRESS)) {
    Serial.println(F("SSD1306 allocation failed"));
    for(;;); // Don't proceed, loop forever
  }

//   if (!display.begin(SCREEN_ADDRESS)) {
//     Serial.println(F("SH110X allocation failed"));
//     for (;;)
//       ;  // Don't proceed, loop forever
//   }

  // Clear the buffer
  display.clearDisplay();

  introMessage();
  // Run game in loop
  while(1){
    if (Serial.available()){
      if(Serial.parseInt()==1){
        play();
      }
    }
  }
}

void loop() {
  // put your main code here, to run repeatedly:

}

void introMessage(){
  display.setTextSize(1);             // Draw 2X-scale text
  display.setTextColor(SSD1306_WHITE);
  display.setCursor(10,5);
  display.println("Dino Game");
  

  display.setTextSize(1);
  
//   display.setCursor(5,45);
  display.println("Enter 1 To Play ");

  display.display();
}

// Move dino function
// void moveDino(int16_t *y, int type=0){
//   display.drawBitmap(DINO_INIT_X, *y, dino1, DINO_WIDTH, DINO_HEIGHT, SSD1306_WHITE);
// }
void moveDino(int16_t *y, int type = 0) {
  display.drawBitmap(DINO_INIT_X, *y, dino1, DINO_WIDTH, DINO_HEIGHT, SSD1306_WHITE);
}

// Move tree funciton
// void moveTree(int16_t *x, int type=0){
//   if(type==0){
//     display.drawBitmap(*x, TREE_Y, tree1, TREE1_WIDTH, TREE1_HEIGHT, SSD1306_WHITE);
//   }
//   else if(type==1){
//     display.drawBitmap(*x, TREE_Y, tree2, TREE2_WIDTH, TREE2_HEIGHT, SSD1306_WHITE);
//   }
  
// }
void moveTree(int16_t *x, int type = 0) {
  if (type == 0) {
    display.drawBitmap(*x, TREE_Y, tree1, TREE1_WIDTH, TREE1_HEIGHT, SSD1306_WHITE);
  } else if (type == 1) {
    display.drawBitmap(*x, TREE_Y, tree2, TREE2_WIDTH, TREE2_HEIGHT, SSD1306_WHITE);
  }
}


// Game over display with score
void gameOver(int score=0){
  display.clearDisplay();

  display.setTextSize(1);             // Draw 2X-scale text
  display.setTextColor(SSD1306_WHITE);
  display.setCursor(10,5);
  display.println("Game Over");
  

//   display.setTextSize(1);

//   display.setCursor(10,30);
  display.println("Score: " + String(score));
//   display.print(score);

  
//   display.setCursor(1,45);
  display.println("Enter 1 To Play Again");

  display.display();
}

// Display score while running the game
void displayScore(int score){
  display.setTextSize(1);
  display.setCursor(64,10);
  display.print("Score: ");
  display.print(score);
}
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

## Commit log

2023-09-27 add sch of samd11
    [BugCON2023_samd11.kicad_pcb, BugCON2023_samd11.kicad_sch, BugCON_2023.kicad_pcb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]
2023-09-29 Change Place_OLED
    [128x32-OLED.STEP, BugCON_2023.kicad_pcb, BugCON_2023.kicad_sch]
2023-09-29 add pcb size, footprints & 3D
    [BugCON2023_samd11.kicad_pcb, BugCON2023_samd11.kicad_sch]
2023-09-29 add pins of usb on samd11
    [BugCON2023_samd11.kicad_pcb, BugCON2023_samd11.kicad_sch]
2023-10-03 add floorplan to samd11
    [BugCON2023_samd11.kicad_pcb, BugCON2023_samd11.kicad_sch]
2023-10-05 fix usb traces & add 3d models
    [12BH331P-GR--3DModel-STEP-56544.STEP, BugCON_2023.kicad_pcb, ESP32-S3-WROOM-1-N8R2.step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]
2023-10-06 upd floorplan on samd11
    [BugCON2023_samd11.kicad_pcb]
2023-10-11 upd BOM on Samd11 badge
    [BugCON2023_samd11.kicad_pcb, BugCON2023_samd11.kicad_sch]
2023-10-11 upd BOM on esp32 badge
    [BugCON_2023.kicad_sch]
2023-10-11 fix 3.3v label on esp32 badge
    [BugCON_2023.kicad_pcb, BugCON_2023.kicad_sch]
2023-10-11 change battery connector
    [BugCON2023_samd11.kicad_pcb, BugCON2023_samd11.kicad_sch]
2023-10-13 upd routing and pad connector on samd11
    [BugCON2023_samd11.kicad_pcb, BugCON2023_samd11.kicad_sch]
2023-10-17 add serial on SAMD11
    [BugCON2023_samd11.kicad_pcb, BugCON2023_samd11.kicad_sch]
2023-10-17 remove 3.3v on Serial connector on esp32s3
    [BugCON_2023.kicad_pcb, BugCON_2023.kicad_sch]
2023-10-17 add logo version speaker
    [BugCON_2023.kicad_pcb]
2023-10-17 add more logos
    [BugCON_2023.kicad_pcb]
2023-10-17 change MCU for RP2040
    [BugCON2023_samd11.kicad_pcb, BugCON2023_samd11.kicad_sch]
2023-10-19 upd floorplan on rp2040 badge
    [BugCON2023_samd11.kicad_pcb, BugCON2023_samd11.kicad_sch]
2023-10-19 Change_LED´s_Change_Touch_Pad
    [BugCON_2023.csv, BugCON_2023.kicad_pcb, BugCON_2023.kicad_sch]
2023-10-19 Start new routing RP2040
    [BugCON2023_samd11.kicad_pcb, BugCON2023_samd11.kicad_sch]
2023-10-20 Update routing RP2040
    [BugCON2023_samd11.kicad_pcb, BugCON2023_samd11.kicad_sch]
2023-10-20 upd BOM and upd silkscreen on RP2040
    [BugCON2023_samd11.kicad_pcb, BugCON2023_samd11.kicad_sch]
2023-10-23 add labels
    [BugCON2023_samd11.kicad_pcb]
2023-10-23 change buttons to the front and remove pull up resistors
    [BugCON2023_samd11.kicad_pcb, BugCON2023_samd11.kicad_sch]
2023-10-23 Add logos
    [BugCON2023_samd11.kicad_pcb]
2023-10-23 Rename_Pullup´s
    [BugCON2023_samd11.kicad_sch]
2023-10-24 add label fboot
    [BugCON2023_samd11.kicad_pcb]
2023-11-04 feat: add esp32s3 support
2023-11-06 test: custom uart pins rp2040
2023-11-06 feat: modify ezbutton library to work with touch sensors
2023-11-07 refactor: buttons definitions
2023-11-08 refactor: buttons
2023-11-09 feat: move selected option with buttons
2023-11-09 feat: run dino game with buttons
2023-11-09 feat: left button return to main menu in dino game
2023-11-10 fix: long press animation on esp32
    [menu.cpp]
2023-11-10 feat: print hardware info
2023-11-12 fix: esp32 s3 touch sensor not working
    [Badge.ino, hardware.h, menu.cpp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]
2023-11-12 fix: menu buffer overflow
    [menu.cpp]
2023-11-13 feat: add leds menu
2023-11-13 fix: disable old left touch pin
    [hardware.h, menu.cpp]
2023-11-14 fix: left touch threshold
    [Badge.ino]
2023-11-15 fix: display repeated talks
    [UartCommunication.cpp, menu.cpp, menu.h]
2023-11-16 fix: serial pins esp32s3
    [Debug.cpp, UartCommunication.cpp, menu.cpp]
2023-11-16 fix: broken talk words
    [UartCommunication.cpp, menu.cpp]
2023-11-17 fix: display all talks
    [menu.cpp]
2023-11-17 fix: display single line talks
    [Badge.ino, UartCommunication.cpp, menu.cpp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]
2023-11-17 feat: add bugcon logo
    [menu.cpp]
2023-11-17 fix: conference list memory overflow
    [UartCommunication.cpp, menu.cpp]
2023-11-18 feat: add leds startup animation
2023-11-18 feat: control leds with the terminal
2023-11-19 fix: show terminal banner more than once
    [Debug.cpp, UartCommunication.cpp, menu.cpp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]
2023-11-21 fix: leds animation order
    [menu.cpp, menu.h]
2023-11-22 feat: change color of leds from the server
2023-11-22 feat: change neopixel pin
2023-11-22 feat: add pico core support
2023-11-22 feat: add flash storage using pico core
